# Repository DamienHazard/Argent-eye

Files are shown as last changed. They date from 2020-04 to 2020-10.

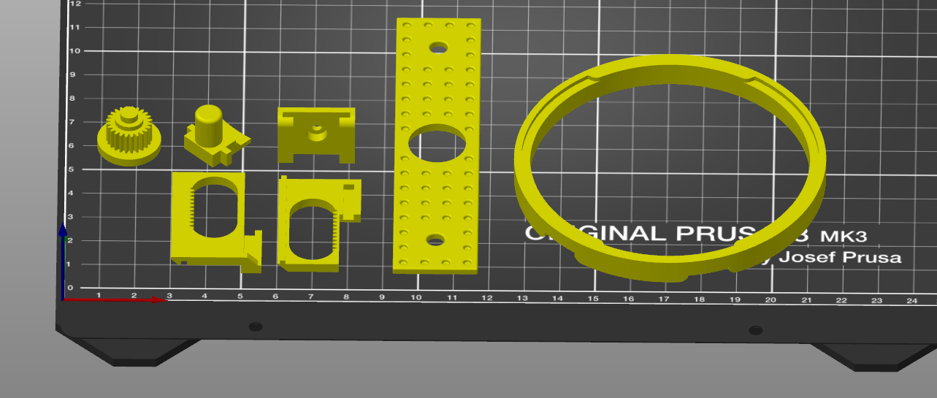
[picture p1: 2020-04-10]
Print_orientation_guide_2.png

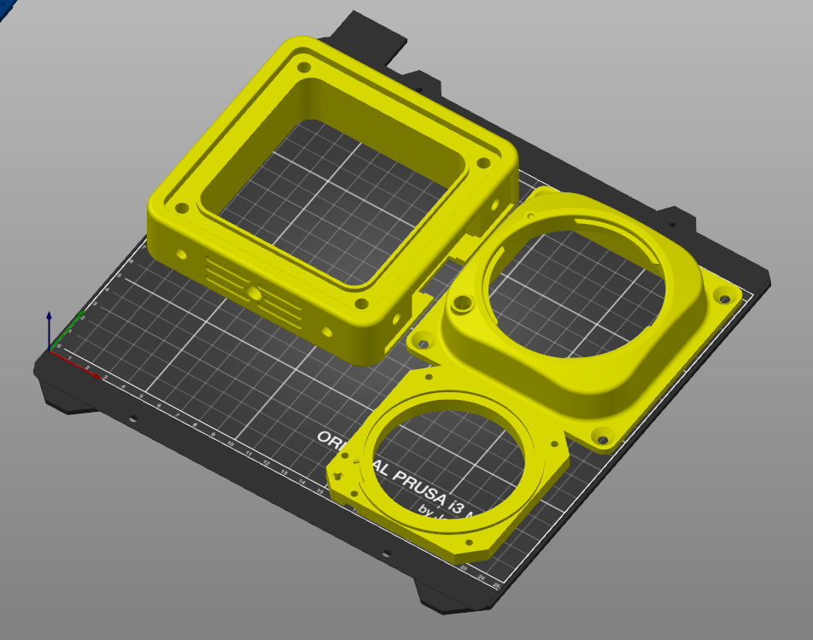
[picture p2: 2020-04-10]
Print_orientation_guide_1.png

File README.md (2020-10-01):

LICENSE
------

This work is licensed under the Creative Commons Attribution-NonCommercial-ShareAlike 4.0 International License. 
To view a copy of this license, visit http://creativecommons.org/licenses/by-nc-sa/4.0/.

README
-------
Argent eye 3D Printable camera made by Damien A.W. Humby.
Github: https://github.com/DamienHazard/Argent-eye

This project is currently in it's beta phase. This is not a final/optimal product.
Please only print this if you're prepared to test it and troubleshoot. 
Please report any issues on github and feel free to join my discord at to share ideas or to discuss the design: https://discord.gg/pZJWvrY

in order to be able to use the camera, please check out the Instruction sheet.

IMPORTANT : The camera needs a mamiya press lens, M-adapter and rollfilm back to be used.
------

Social
------
If you share your builds on instagram or twitter, be sure to use the #HumbyProductdesign or #Humbyargenteye hashtags so people can see the wide range of builds out there.(and for proper attribution, you know)

CHANGELOG
------

v0.5 BETA RELEASE.
     Initial public release

V1.0 Pre_release
     
  Changes:
   - Added coldshoes
   - Added New flange lock
   - Added extra inserts for grip/accessory mounting
   - Redesigned Adapter locks
   
v.1.1
   - Added new grips with better ergonomics.
   - Added community mod of the  new grips with an extra holes. (QoL mod by Kitingmare)

BOM links
------

M5 brass inserts: https://www.amazon.co.uk/threaded-RX-M5x9-5-Threaded-Press-fit-ultrasound/dp/B07YSVXWS8
m3 brass inserts: https://www.amazon.co.uk/ruthex%C2%AE-threaded-RX-M3x5-Press-fit-ultrasound/dp/B07YSRGZ9N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

DONATE
-----
Projects like this aren't cheap, and I've dedicated a lot of my time to work on this, so if you wish to support me,
please consider donating or share the project with others so we can get as many people as possible to bring this project to the next level.
patreon: https://www.patreon.com/Hazard
Paypal: https://www.paypal.com/cgi-bin/webscr?cmd=_s-xclick&hosted_button_id=YAQUE44D32B9G&source=url

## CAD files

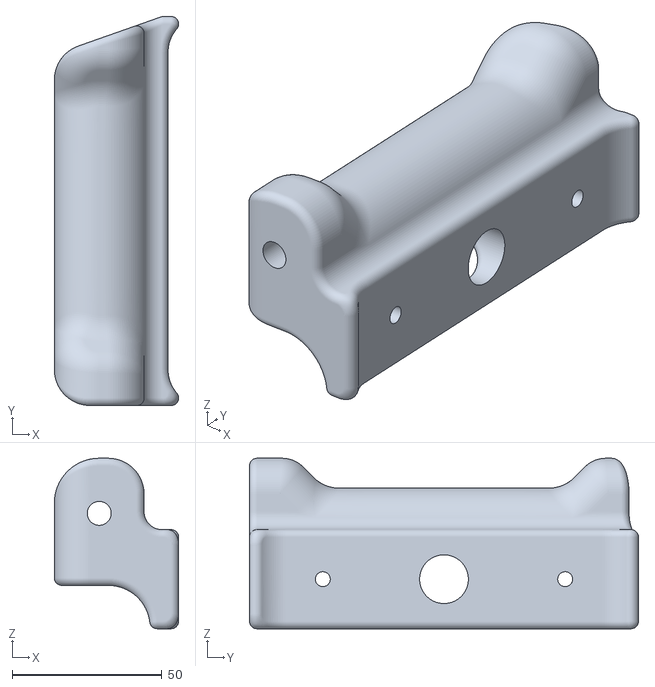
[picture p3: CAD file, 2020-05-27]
Argent_Eye_Press_grip v2.stl
41.5 x 130.0 x 57.0

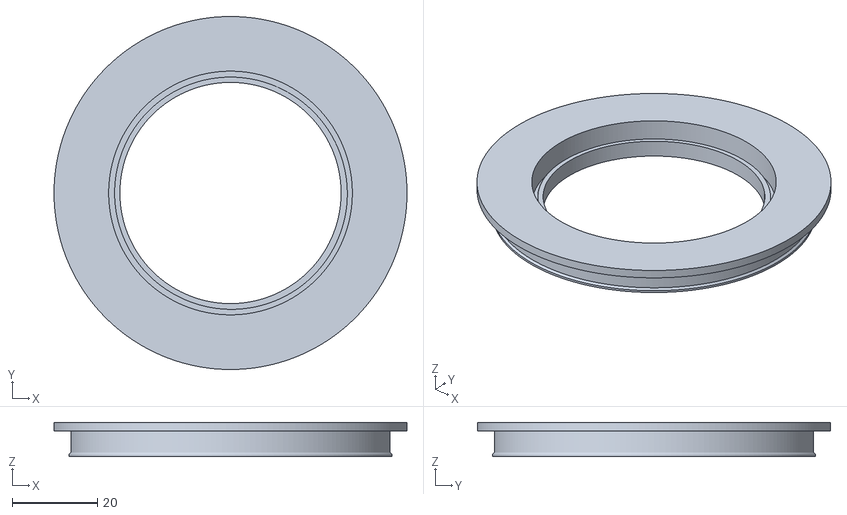
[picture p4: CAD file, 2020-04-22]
RB67_bellows_adapter_experimental.stl
83.0 x 83.0 x 8.00

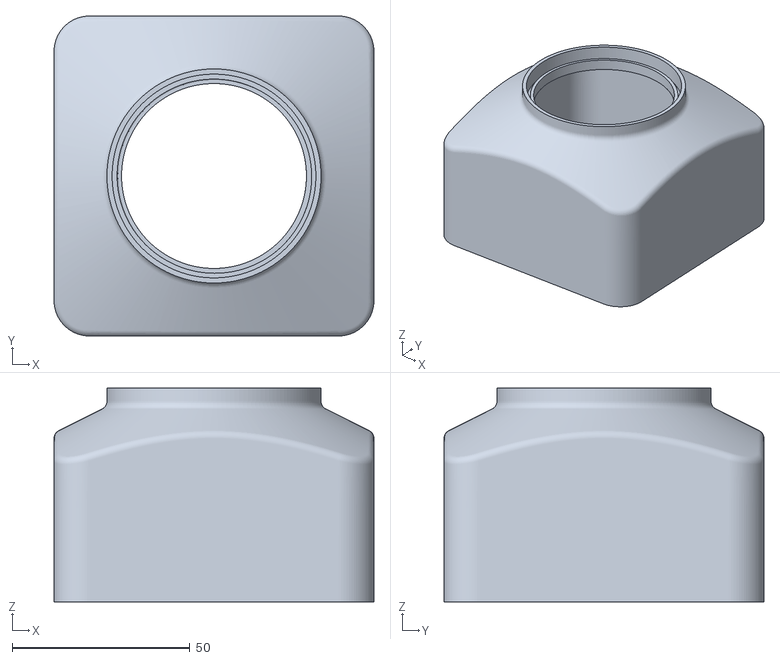
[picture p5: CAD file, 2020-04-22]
LensHood_100mm_experimental.stl
90.0 x 90.0 x 60.1

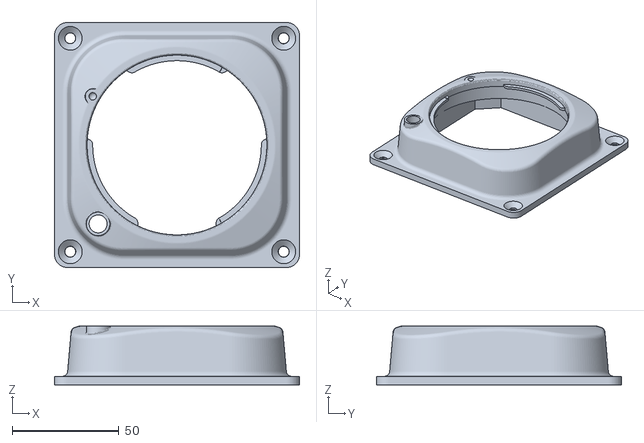
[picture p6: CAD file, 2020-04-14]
Argent_Eye_cone v1.stl
114.8 x 114.8 x 27.5

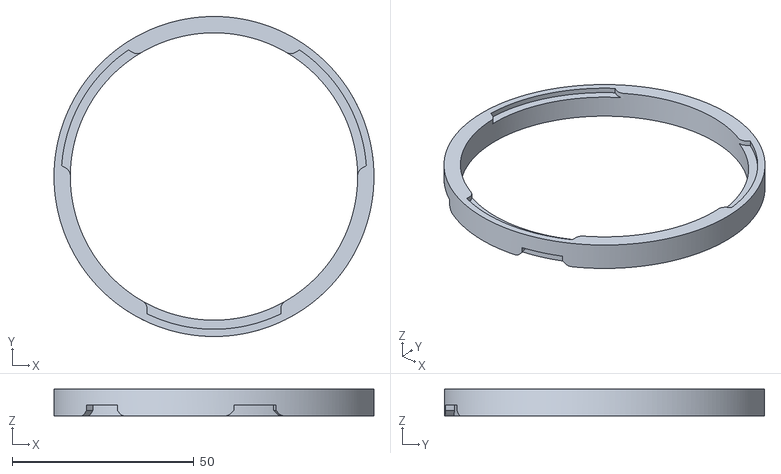
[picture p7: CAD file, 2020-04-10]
Argent_Eye_flange v1.stl
88.0 x 88.0 x 7.40

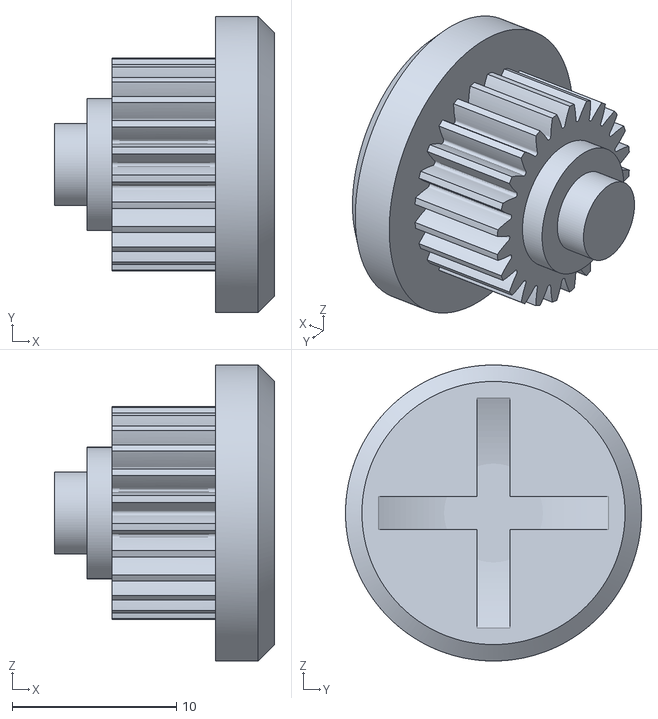
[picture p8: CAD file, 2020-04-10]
Argent_Eye_Knob v1.stl
13.4 x 18.0 x 18.0

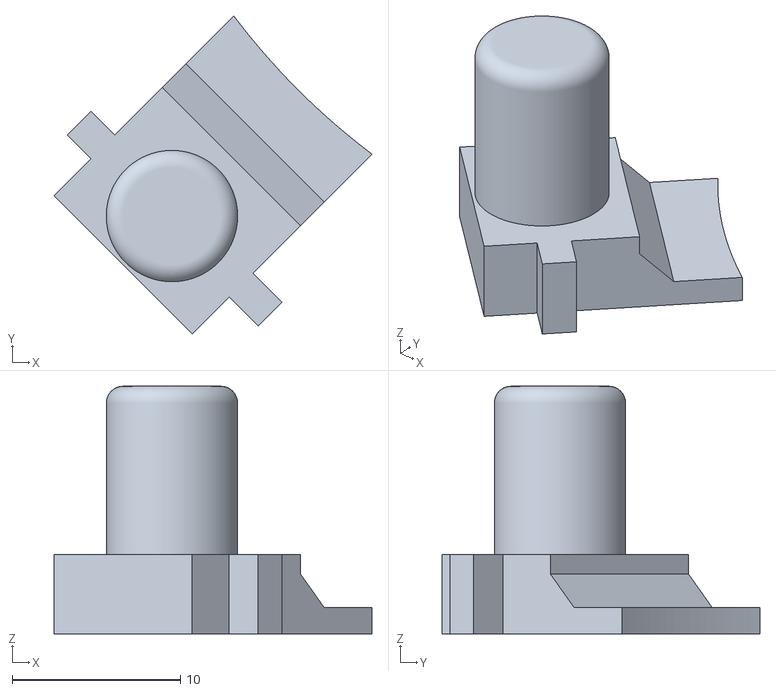
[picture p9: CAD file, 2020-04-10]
Argent_Eye_button v1.stl
18.9 x 18.9 x 14.7

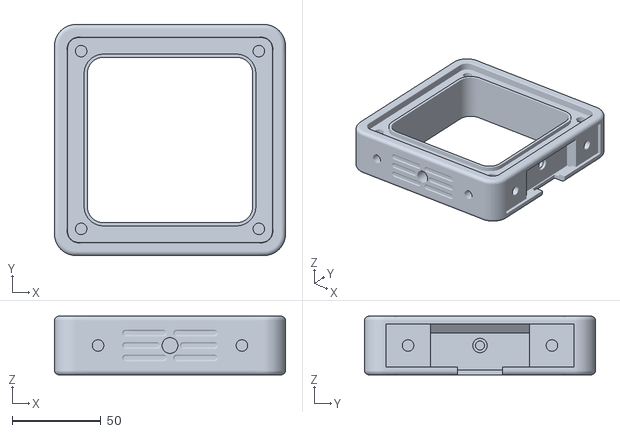
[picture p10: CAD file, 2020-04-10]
Argent_Eye_body v1.stl
130.0 x 130.0 x 33.0

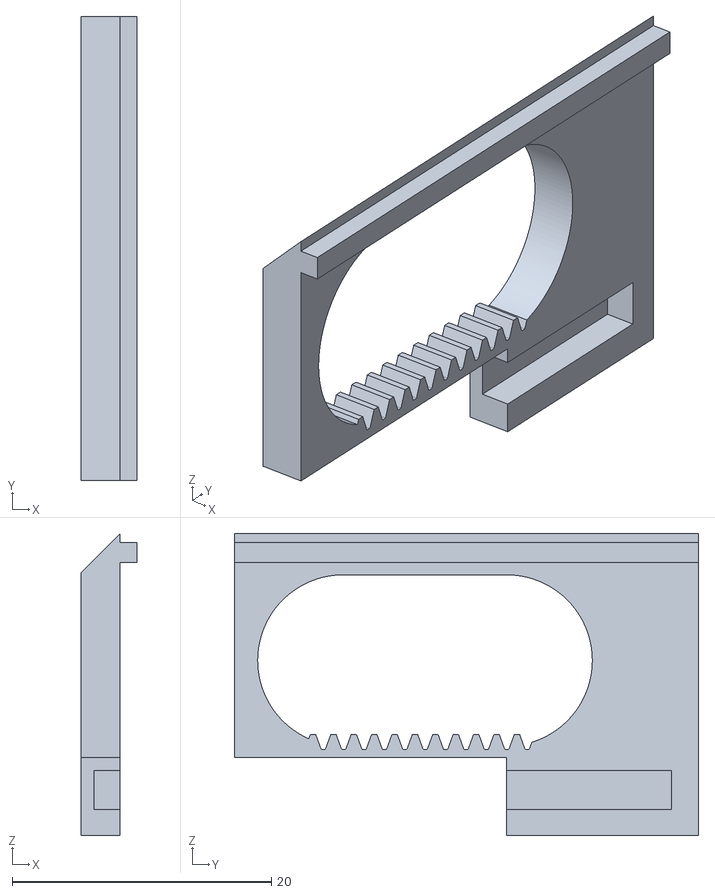
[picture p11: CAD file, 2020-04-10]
Argent_Eye_lock_a v1.stl
4.30 x 35.8 x 23.3

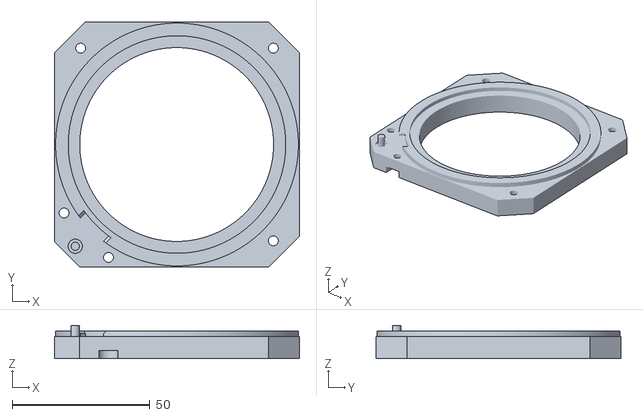
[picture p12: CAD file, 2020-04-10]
Argent_Eye_retainer v1.stl
89.0 x 89.0 x 12.0

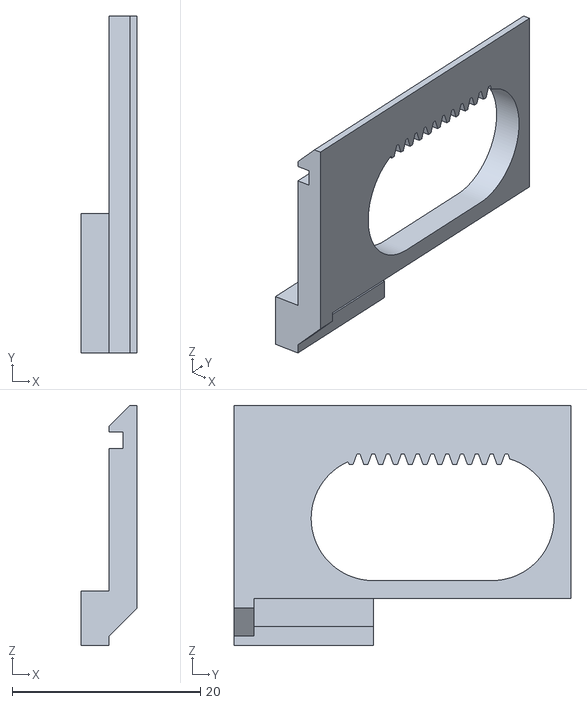
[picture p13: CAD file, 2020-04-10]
Argent_Eye_lock_b v1.stl
6.00 x 35.8 x 25.5

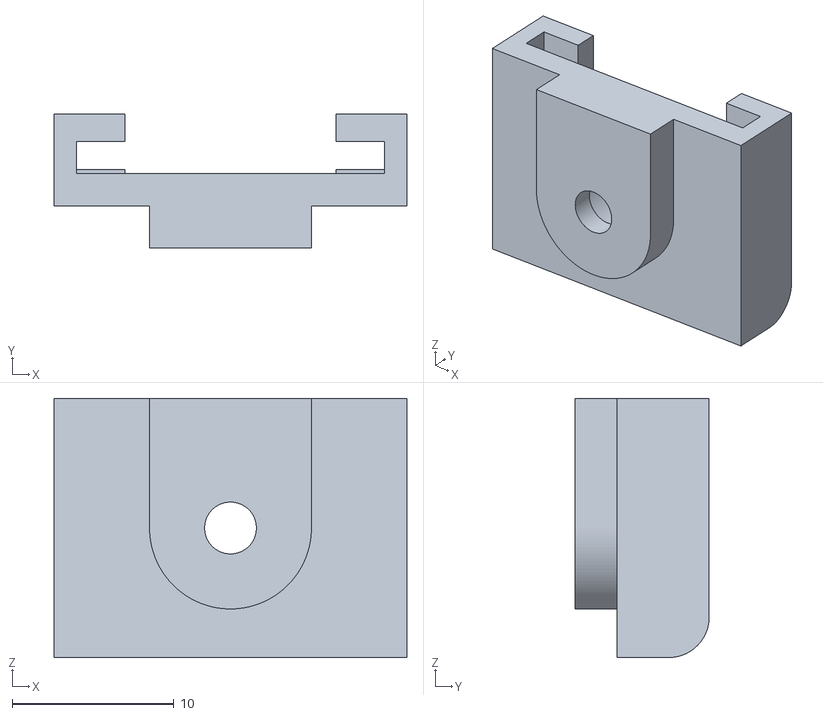
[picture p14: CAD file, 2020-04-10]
Argent_Eye_coldshoe v1.stl
21.8 x 8.30 x 16.0

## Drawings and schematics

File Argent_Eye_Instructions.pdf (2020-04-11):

# Printer settings: Bill of materials

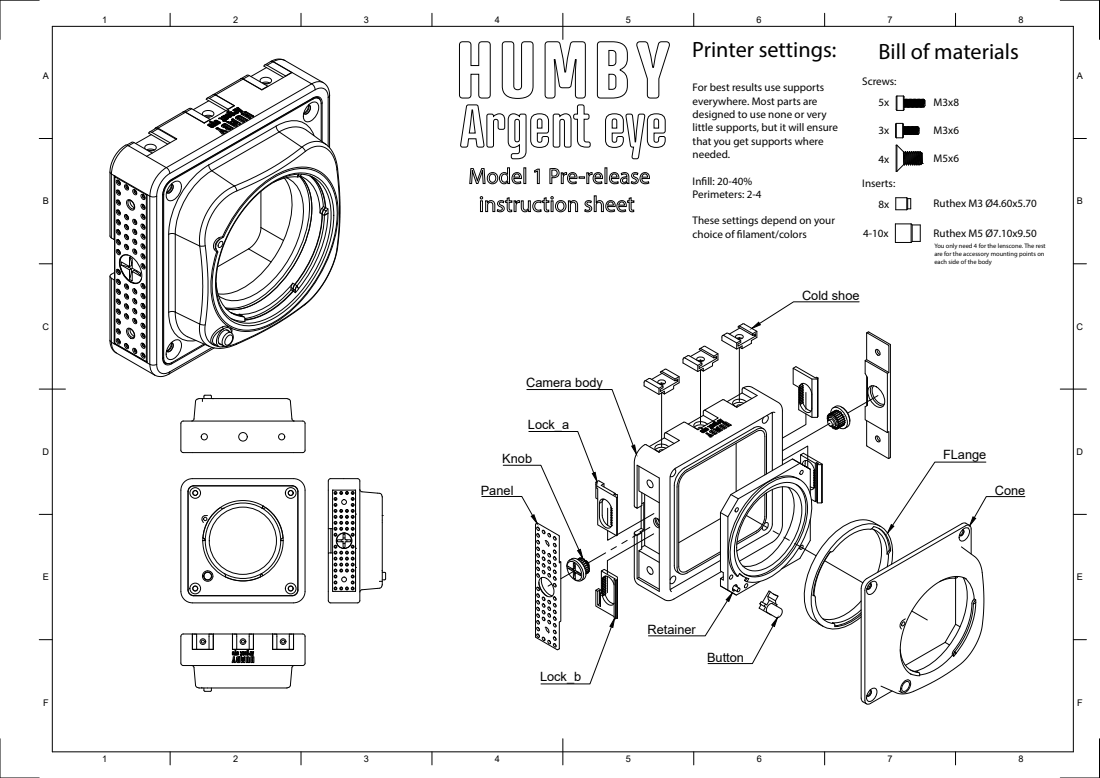
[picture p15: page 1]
Cold shoe; Cone; FLange; Button; Retainer; Lock_a; Panel; Lock_b; Knob; Camera body; Ruthex M3 Ø4.60x5.70; Ruthex M5 Ø7.10x9.50; Inll: 20-40% Perimeters: 2-4; Screws:; Inserts:

For best results use supports
everywhere. Most parts are
designed to use none or very
little supports, but it will ensure
that you get supports where
needed.

These settings depend on your
choice of lament/colors

You only need 4 for the lenscone. The rest
are for the accessory mounting points on
each side of the body

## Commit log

2020-03-16 Added Cone variants
    For users who can't buy the m6 plunger in the BOM, there's now a m3 version that takes an m3 insert and screw.
    [Cone_m3.stl, Cone_m6plunger.stl]
2020-03-16 Deleted old file version
    [Cone.stl]
2020-03-17 Fixed light seals
    There was an issue with tolerances on the light seals. The body and cones have been updated to fix this.
    [Body_v2.stl, Cone_m3_v2.stl, Cone_m6plunger_v2.stl]
2020-03-19 added print orientation guide
    Added a screenshot showing how users should orientate each part for optimal printing. Print settings are up to the user to decide, but extra perimeters could help with blocking light.
2020-03-21 Optimized parts
    It was reported that the retainer was over constrained, so i made to tolerances for the M3 screws looser to allow for some play in case people don't align their inserts perfectly. It's recommended that users buy heat set inserts with guides to keep them aligned, but with the new tolerances it should be more forgiving with generic inserts.
    I also Improved the tolerances of the M5 screw holes as per request, this however has only been done to the set screw(m3) version.
    I will look into updating the Plunger(m6) version too at a later date.
    [Cone_m3_V3.stl, Flange_retainer_v2.stl]
2020-03-21 Delete Cone_m3_v2.stl
    removed an obsolete version
    [Cone_m3_v2.stl]
2020-03-21 Delete Flange_retainer.stl
    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
    [Flange_retainer.stl]
2020-03-23 Removed old version
    [Argent eye.step]
2020-03-23 Added updated step file
    [Argent eye.step]
2020-04-10 Added new verion
    [Argent_Eye_Knob v1.stl, Argent_Eye_body v1.stl, Argent_Eye_button v1.stl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]
2020-04-10 Added print orientation guides
    Added images that display how to orientate(not arrange) the parts for printing.
2020-04-14 tweaked the cone
    No need to re-print.
    [Argent_Eye_cone v1.stl]
2020-04-22 added experimental lens hood
    by experimental I mean that the filter threads are wonky.
    [LensHood_100mm_experimental.stl]
2020-04-22 Added experimental rb67 bellows adapter
    By experimental I mean that the filter threads are wonky
    [RB67_bellows_adapter_experimental.stl]
2020-04-23 Added grip for mamiya press backs
    Added a grip made for meshing with the mamiya press back. the grip comes with a M8 hole for cable releases
    [Argent_eye_Press_grip v1.stl]
2020-05-27 Updated press grip
    [Argent_Eye_Press_grip v2.stl]
2020-10-01 Added a community variant by Kitingmare
    These grips have an additional hole for cables to exit out of for QoL.
